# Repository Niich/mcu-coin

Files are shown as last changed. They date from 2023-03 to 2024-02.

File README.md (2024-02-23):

# mcu-coin
## Design Goals
- make a device that is similare in form factor to military challange coins
- production cost needs to be in the range of traditional coins ($5-$15)

## V1.0 features
- based on ESP32C3
- 100mAh 302020 battery
- 7 addressable RGBs
- 2 GPIO buttons
- hardware power on/off and boot select **
    - to reduce power draw when off and to guard against bad firmare bricking the device since once it is assembled, battery soldered in and parts glued together, removing power to reset device would be very difficult.
- USB charging
- wireless charging ***
- WiFi ***
- bluetooth ***

** not working on original design but manual fix found

*** Currently not working

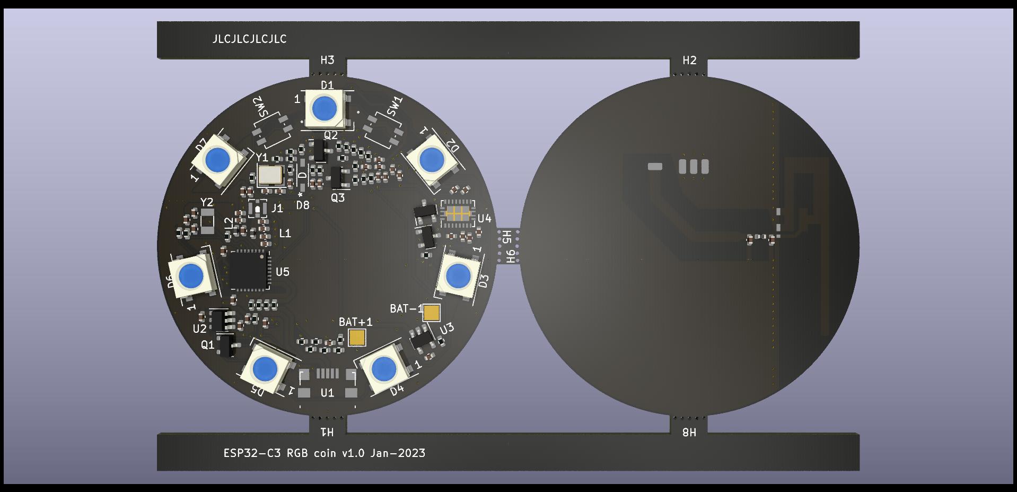
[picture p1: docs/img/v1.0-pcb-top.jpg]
pcb top view

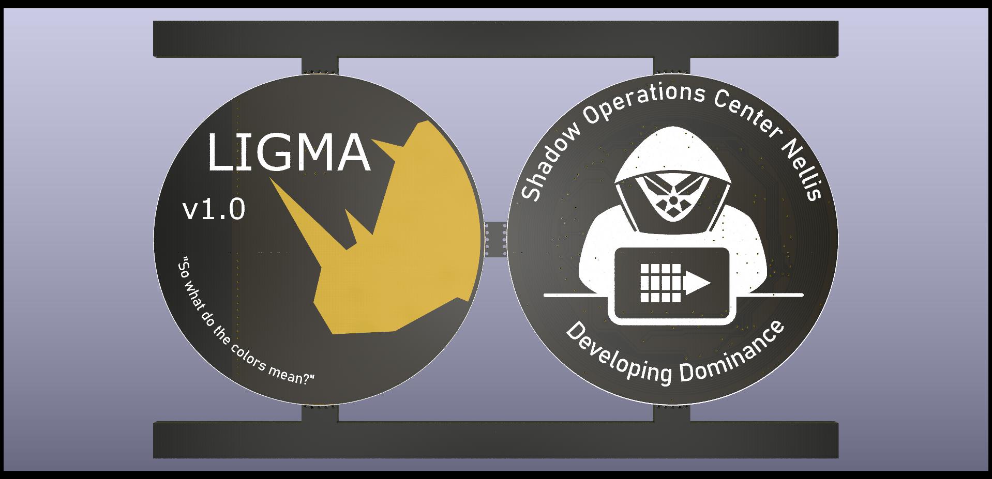
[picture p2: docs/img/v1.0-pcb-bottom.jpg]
pcb bottom view

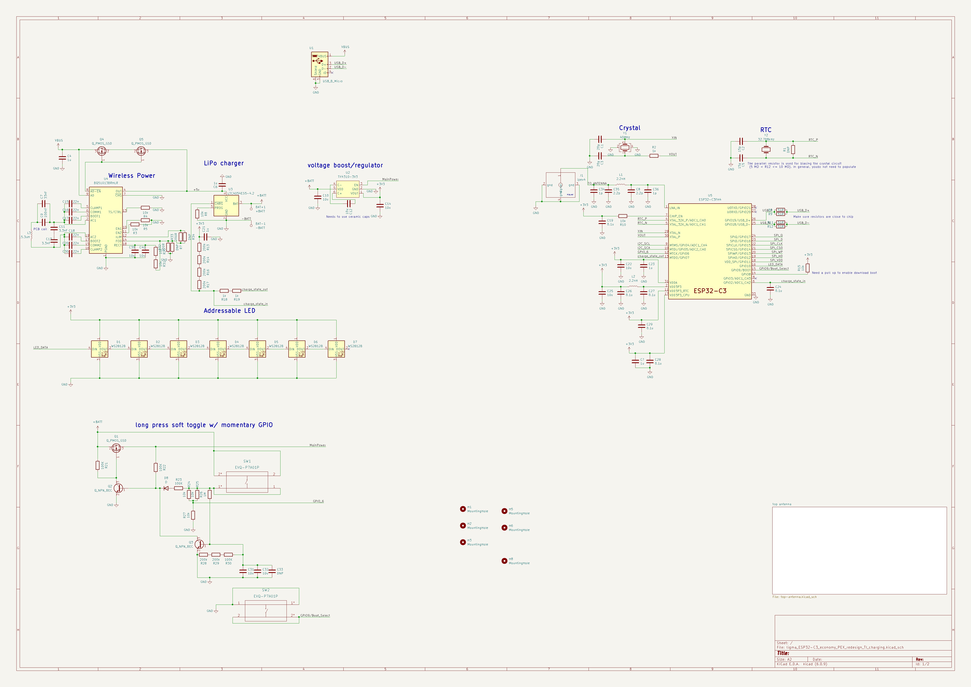
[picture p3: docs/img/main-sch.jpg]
schematic main

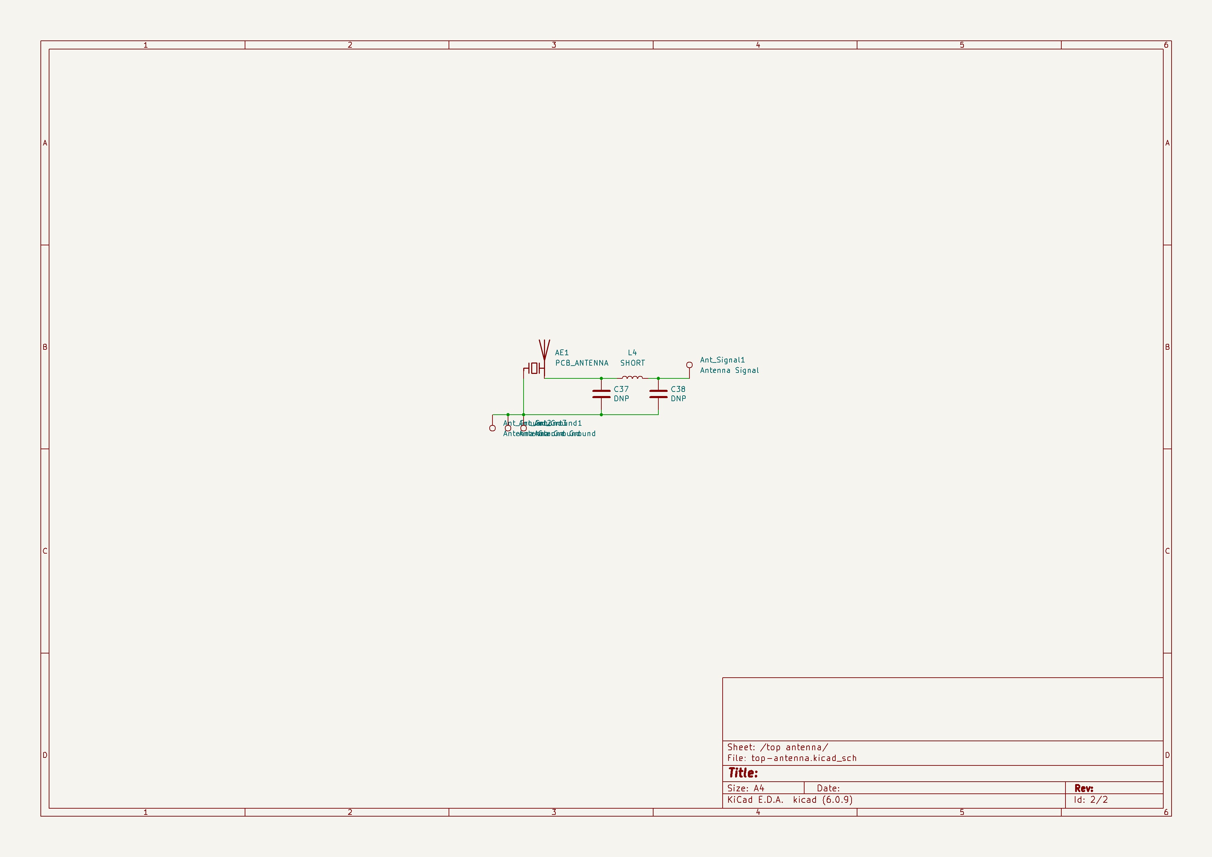
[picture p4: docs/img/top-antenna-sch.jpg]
schematic antenna


## v1.0 known issues
- ✅ SW2 boot select button/GPIO9 
    - **Expected:** when held during boot ESP enters flashing mode.
    - **Observed:** device does not enter boot mode when button is held during boot.
    - **Fix:** After reviewing the ESP docs and the schematic issue was found to be that the button was connected to 3.3v instead of ground. Fixed by cutting trace to +3.3 and bridging the pin to the ground plane.
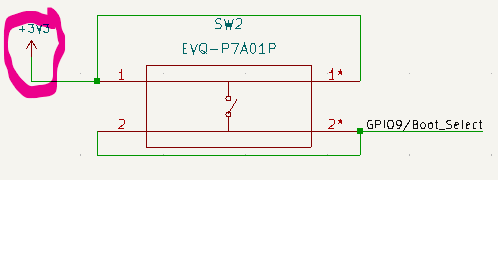
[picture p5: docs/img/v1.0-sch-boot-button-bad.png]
image of incorrect boot select layout
    
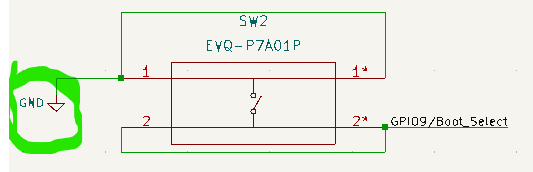
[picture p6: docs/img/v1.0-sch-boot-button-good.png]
image of incorrect boot select layout
    
- ✅ SW1 on-off/GPIO6 
    - **Expected:** when device is off pressing this button should turn on the device. while device is active quick presses should be detected on GPIO6. Long pressing when "on" should turn off the device. 
    - **Observed:** Button does not turn the device on. but once on the press can be detected on GPIO6 and long press does turn the device off.
    - **Fix:** After reviewing the schematic issue was found to be that the button was connected to "MainPower" instead of +BATT. meaning that when the device is off there is no voltage on the switch so pressing it did nothing. Fix is connecting the button to +BATT and cutting trace to "MainPower"
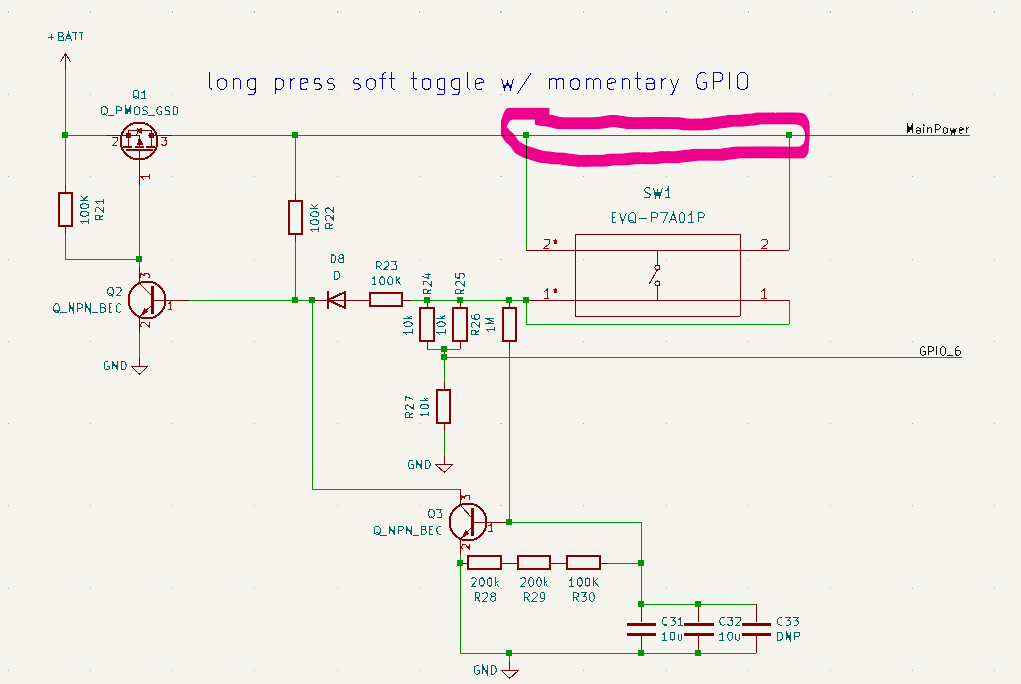
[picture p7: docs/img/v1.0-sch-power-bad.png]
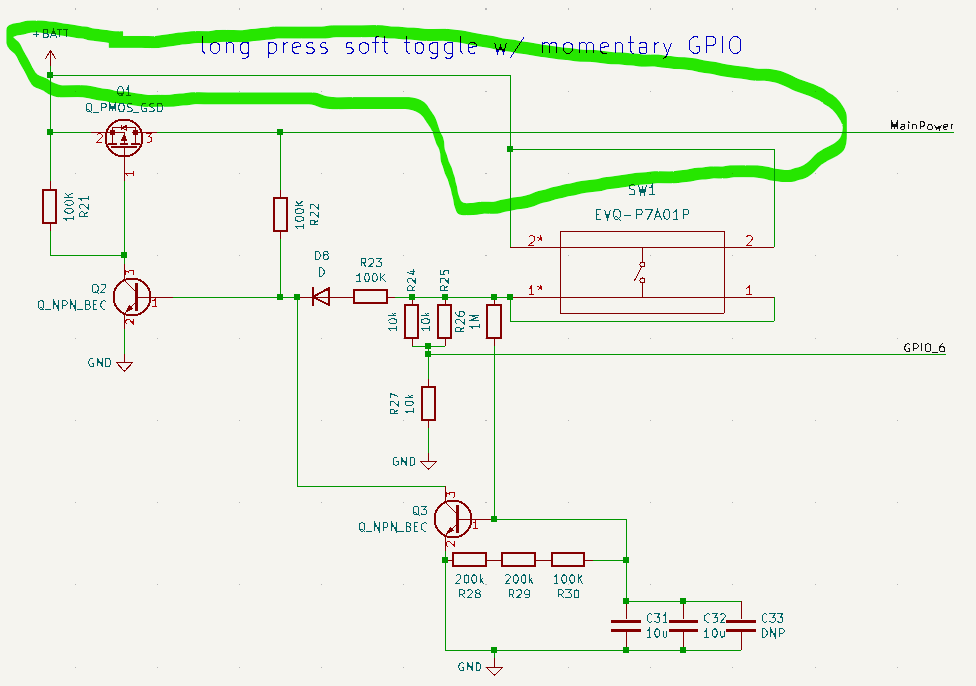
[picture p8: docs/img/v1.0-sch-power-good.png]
    
- ❌ Wireless charging
    - **Expected:** when device placed on wireless charging pad it charges
    - **Observed:** Pad detects device but power delivery never stabalises it seems to be failing the negotiation. Issue has been observed on two differant wireless power transmitters
    - **Fix:** NONE. This is due to poor efficiency. If placed just right, wireless charging will work, but devices get VERY hot. To resolve this, the coil needs to be measured and revised in future designs. Additionally, the QI standard specifies a ferite layer behind the coil, which is not possible with the current placement of the coil.
- ❌ 2.4Ghz wireless (WifI/bluetooth)
    - **Expected:** device connects to WiFi.
    - **Observed:** When 2.4Ghz functions are enabled in firmware the device crashes. 
    - **Fix:** NONE. This is related to the luckup/crashing. When WiFi is activated, it interferes with the main clock and causes the device to lockup/crash.
- ❌ Crashing and hard locks
    - **Expected:** Device runs coninualy until turned of or battery is drained.
    - **Observed:** The device runs for a while but randomly locks up and requires a restart. The issue seems worse when LEDs are at full power.
    - **Fix:** NONE: This is caused by bad placement and routing of the main clock signal. Due to poor design, there is interferance and cross-talk that degrade the clock signal and cause CPU lockup.
- [ ] Acrylic spacer and diffuser
    - **Expected:** Top and bottom PCB are seperated and atteched to a 3mm acrylic spacer.
    - **Observed:** Although the 302020 battery is listed as 3mm thick it is actualy slightly larger so the acrylic part is not thick enought to connect both sides without bending and placing pressure on the LiPo battery
    - **Ideas:** Make a thicker spacer. 1/8" might be ehough since that is 3.17mm

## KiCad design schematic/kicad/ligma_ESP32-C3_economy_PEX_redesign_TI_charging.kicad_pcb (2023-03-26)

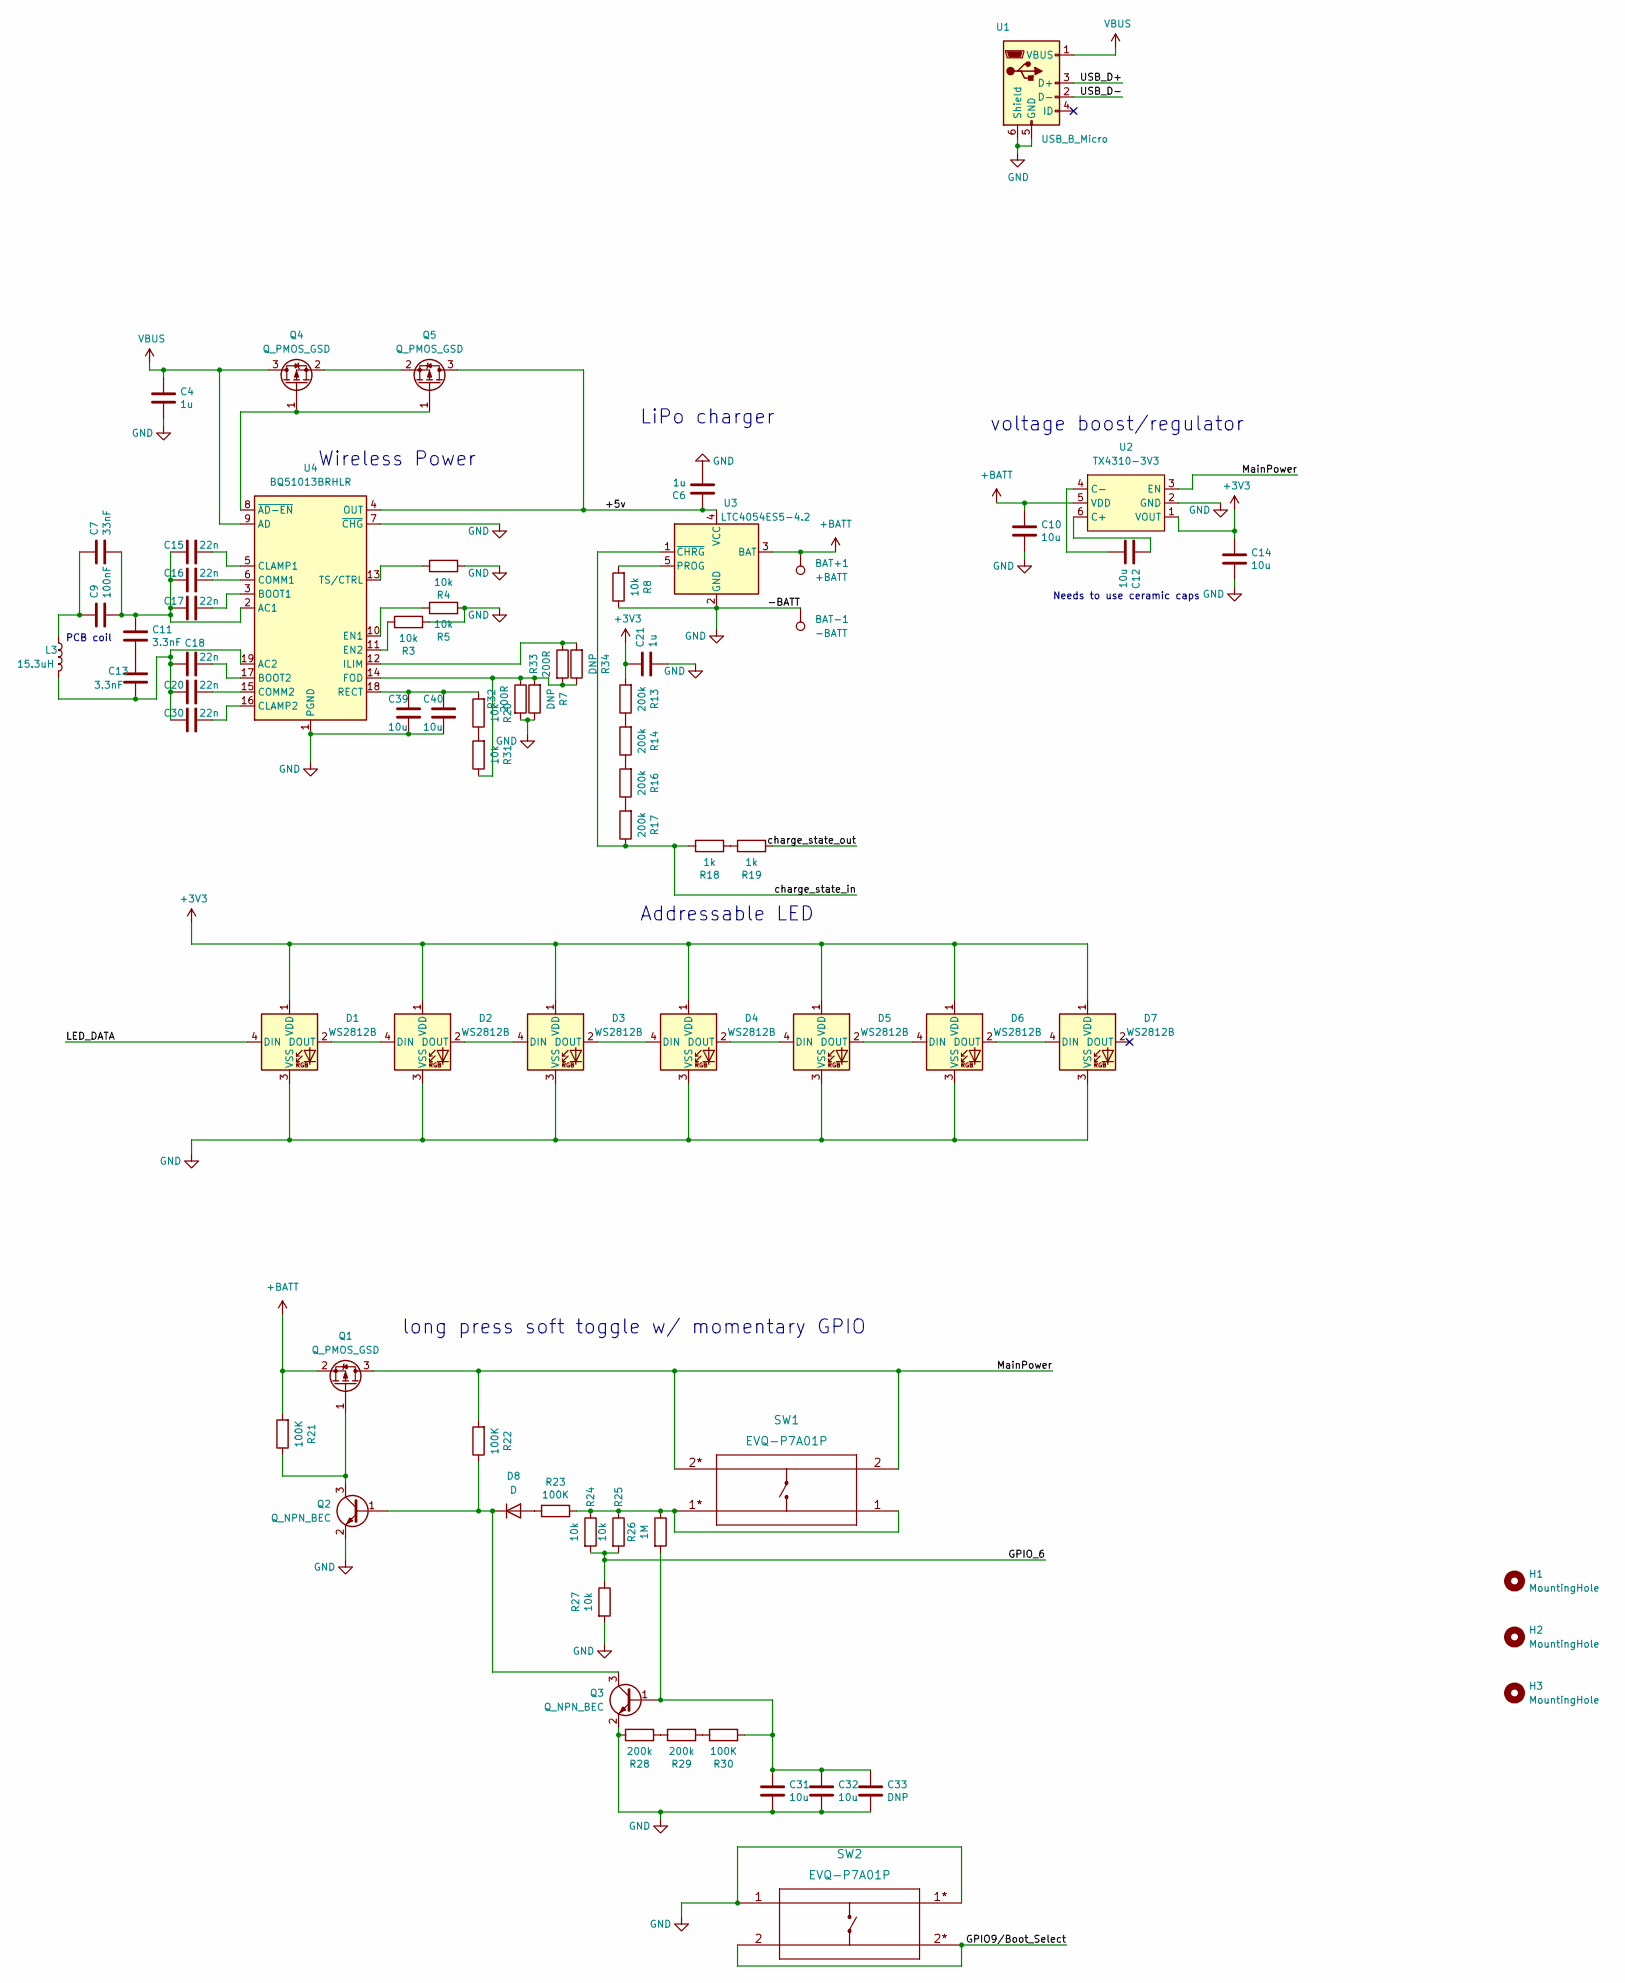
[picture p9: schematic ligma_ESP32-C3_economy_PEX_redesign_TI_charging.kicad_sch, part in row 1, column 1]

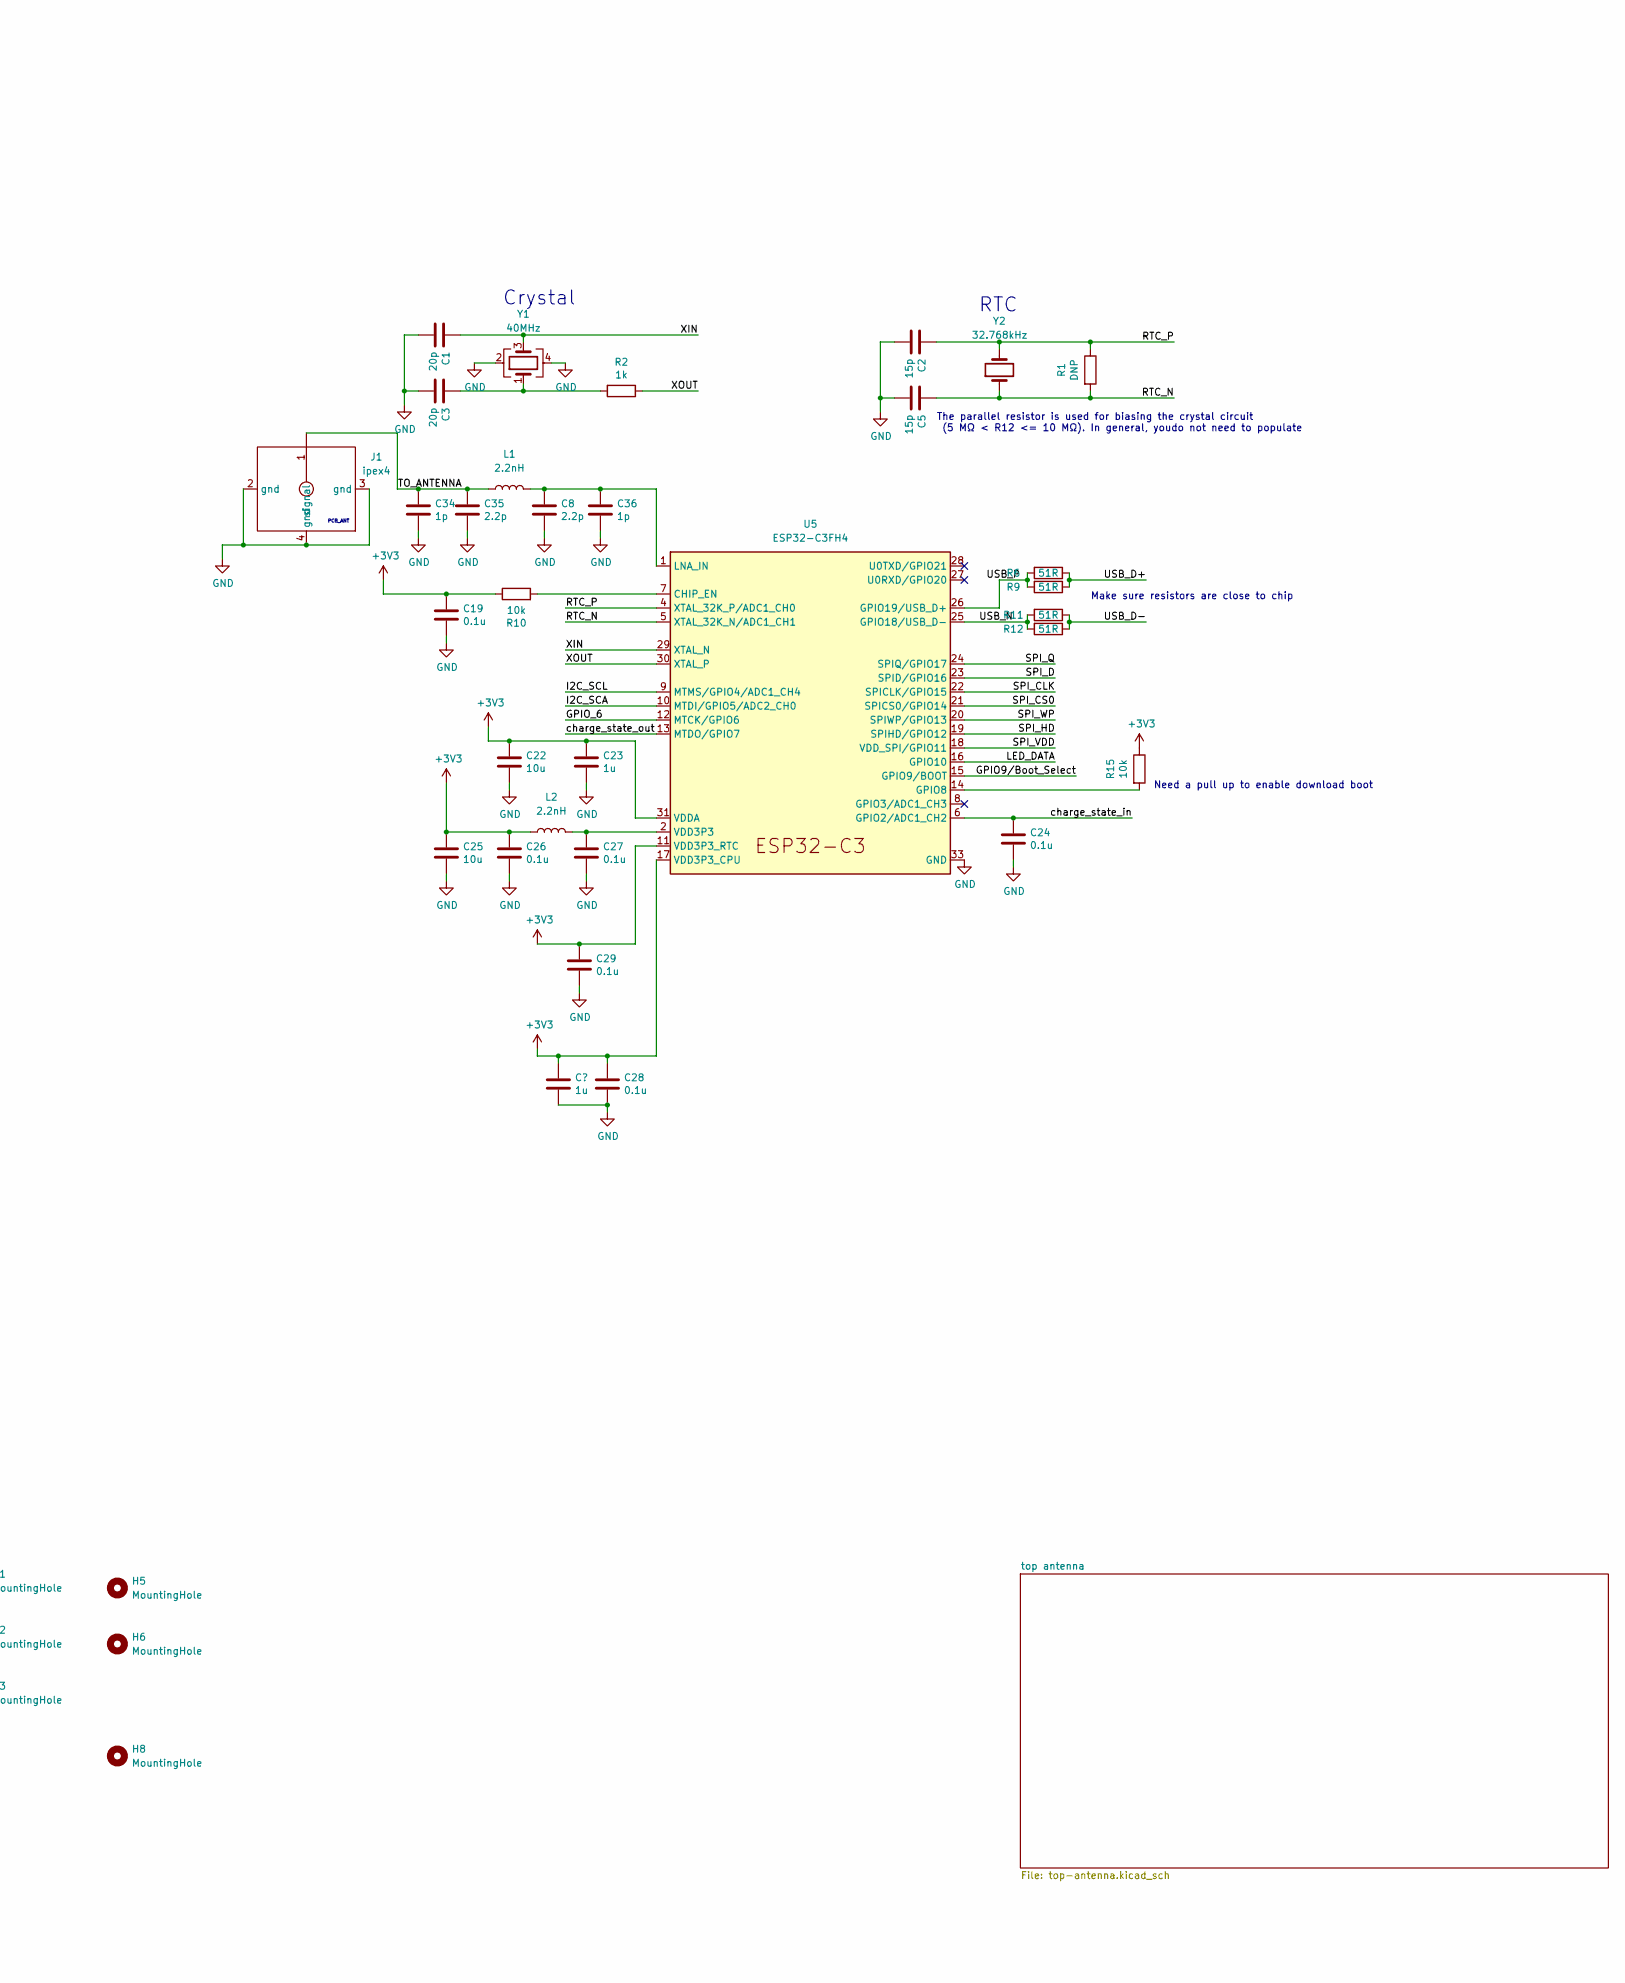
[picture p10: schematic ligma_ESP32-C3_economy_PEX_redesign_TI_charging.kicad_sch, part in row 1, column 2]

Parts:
BAT+1: +BATT; TestPoint_Pad_2.0x2.0mm
BAT-1: -BATT; TestPoint_Pad_2.0x2.0mm
C1, C3: 20p; C_0402_1005Metric; MFR.Part # 0402CG200J500NT; LCSC Part # C1554
C2, C5: 15p; C_0402_1005Metric; MFR.Part # 0402CG150J500NT; LCSC Part # C1548
C4, C6, C21, C23: 1u; C_0402_1005Metric; MFR.Part # CL05A105KA5NQNC; LCSC Part # C52923
C7: 33nF; C_0402_1005Metric; MFR.Part # C1585; LCSC Part # C1585
C8, C35: 2.2p; C_0402_1005Metric; MFR.Part # 0402CG2R2C500NT; LCSC Part # C1559
C9: 100nF; C_0402_1005Metric; MFR.Part # CL05B104KB54PNC; LCSC Part # C307331
C10, C12, C14, C22, C25, C31, C32, C39, C40: 10u; C_0402_1005Metric; MFR.Part # CL05A106MQ5NUNC; LCSC Part # C15525
C11, C13: 3.3nF; C_0402_1005Metric; MFR.Part # CL05B332KB5NNNC; LCSC Part # C26404
C15, C16, C17, C18, C20, C30: 22n; C_0402_1005Metric; MFR.Part # 0402B223K500NT; LCSC Part # C1532
C19, C24, C26, C27, C28, C29: 0.1u; C_0402_1005Metric; MFR.Part # CL05B104KB54PNC; LCSC Part # C307331
C33: DNP; C_0402_1005Metric
C34, C36: 1p; C_0402_1005Metric; MFR.Part # 0402CG1R0C500NT; LCSC Part # C1550
D1, D2, D3, D4, D5, D6, D7: WS2812B; LED_WS2812B_PLCC4_5.0x5.0mm_P3.2mm; MFR.Part # WS2812E-V5; LCSC Part # C2920042
D8: D; SOD_123; MFR.Part # B5819W SL; LCSC Part # C8598
H1, H2, H3, H5, H6, H8: MountingHole; coin-mouse-bite
J1: ipex4; HC-RF-IPEX2020-04; MFR.Part # HC-RF-IPEX2020-04; LCSC Part # C2894921
L1, L2: 2.2nH; L_0402_1005Metric; MFR.Part # CLH1005T-2N2S-S; LCSC Part # C108254
L3: 15.3uH; 15.3uH-coil
Q1, Q4, Q5: Q_PMOS_GSD; SOT-23; MFR.Part # SI2301CDS-T1-GE3; LCSC Part # C10487
Q2, Q3: Q_NPN_BEC; SOT-23; MFR.Part # FHS3904-ME; LCSC Part # C336147
R1, R7, R34: DNP; R_0402_1005Metric
R2, R18, R19: 1k; R_0402_1005Metric; MFR.Part # 0402WGF1001TCE; LCSC Part # C11702
R3, R4, R5: 10k; R_0402_1005Metric; MFR.Part # 0402WGF1000TCE; LCSC Part # C25744
R6, R9, R11, R12: 51R; R_0402_1005Metric; MFR.Part # 0402WGF5100TCE; LCSC Part # C25123
R8, R10, R15, R20, R24, R25, R27, R31: 10k; R_0402_1005Metric; MFR.Part # 0402WGF1002TCE; LCSC Part # C25744
R13, R14, R16, R17, R28, R29: 200k; R_0402_1005Metric; MFR.Part # 0402WGF2003TCE; LCSC Part # C25764
R21, R22, R23, R30: 100K; R_0402_1005Metric; MFR.Part # 0402WGF1003TCE; LCSC Part # C25741
R26: 1M; R_0402_1005Metric; MFR.Part # 0402WGF1004TCE; LCSC Part # C26083
R32, R33: 200R; R_0402_1005Metric; MFR.Part # 0402WGF2000TCE; LCSC Part # C25087
SW1, SW2: EVQ-P7A01P; MFR.Part # EVQP7A01P; LCSC Part # C79167
U1: USB_B_Micro; USB-Micro-B-BTC-MC5S-42; MFR.Part # BTC-MC5S-42; LCSC Part # C2908213
U2: TX4310-3V3; SOT-23-6; MFR.Part # TX4310B; LCSC Part # C448640
U3: LTC4054ES5-4.2; TSOT-23-5; MFR.Part # TP4054-42-SOT25R; LCSC Part # C32574
U4: BQ51013BRHLR; Texas_VQFN-RHL-20; MFR.Part # BQ51013BRHLR; LCSC Part # C55663
U5: ESP32-C3FH4; QFN-32-1EP_5x5mm_P0.5mm_EP3.45x3.45mm; MFR.Part # ESP32-C3FH4; LCSC Part # C2858491
Y1: 40MHz; Crystal_SMD_3225-4Pin_3.2x2.5mm; MFR.Part # 3S40000131; LCSC Part # C516573
Y2: 32.768kHz; Crystal_SMD_3215-2Pin_3.2x1.5mm; MFR.Part # Q13FC1350000400; LCSC Part # C32346

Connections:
+BATT: BAT+1.1, C10.1, Q1.2 (S), R21.2, U2.5 (VDD), U3.3 (BAT)
/+5v: C6.1, Q5.3 (D), U3.4 (VCC), U4.4 (OUT)
/GPIO9/Boot_Select: SW2.2, SW2.2*, U5.15 (GPIO9/BOOT)
/GPIO_6: R24.2, R25.2, R27.1, U5.12 (MTCK/GPIO6)
/I2C_SCA: U5.10 (MTDI/GPIO5/ADC2_CH0)
/I2C_SCL: U5.9 (MTMS/GPIO4/ADC1_CH4)
/LED_DATA: D1.4 (DIN), U5.16 (GPIO10)
/MainPower: Q1.3 (D), R22.2, SW1.2, SW1.2*, U2.3 (EN)
/RTC_N: C5.1, R1.2, U5.5 (XTAL_32K_N/ADC1_CH1), Y2.1
/RTC_P: C2.1, R1.1, U5.4 (XTAL_32K_P/ADC1_CH0), Y2.2
/SPI_CLK: U5.22 (SPICLK/GPIO15)
/SPI_CS0: U5.21 (SPICS0/GPIO14)
/SPI_D: U5.23 (SPID/GPIO16)
/SPI_HD: U5.19 (SPIHD/GPIO12)
/SPI_Q: U5.24 (SPIQ/GPIO17)
/SPI_VDD: U5.18 (VDD_SPI/GPIO11)
/SPI_WP: U5.20 (SPIWP/GPIO13)
/TO_ANTENNA: C34.1, C35.1, J1.1 (signal), L1.1
/USB_D+: R6.1, R9.1, U1.3 (D+)
/USB_D-: R11.1, R12.1, U1.2 (D-)
/USB_N: R11.2, R12.2, U5.25 (GPIO18/USB_D-)
/USB_P: R6.2, R9.2, U5.26 (GPIO19/USB_D+)
/XIN: C1.1, U5.29 (XTAL_N), Y1.3
/XOUT: R2.1, U5.30 (XTAL_P)
/charge_state_in: C24.1, R17.1, R18.1, U3.1 (~CHRG), U5.6 (GPIO2/ADC1_CH2)
/charge_state_out: R19.2, U5.13 (MTDO/GPIO7)
GND: BAT-1.1, C1.2, C2.2, C3.2, C4.2, C5.2, C6.2, C8.2, C10.2, C14.2, C19.2, C21.2, C22.2, C23.2, C24.2, C25.2, C26.2, C27.2, C28.2, C29.2, C31.2, C32.2, C33.2, C34.2, C35.2, C36.2, C39.2, C40.2, D1.3 (VSS), D2.3 (VSS), D3.3 (VSS), D4.3 (VSS), D5.3 (VSS), D6.3 (VSS), D7.3 (VSS), J1.2 (gnd), J1.3 (gnd), J1.4 (gnd), Q2.2 (E), Q3.2 (E), R3.2, R4.2, R5.2, R7.1, R8.1, R27.2, R28.1, R32.2, U1.5 (GND), U1.6 (Shield), U2.2 (GND), U3.2 (GND), U4.1 (PGND), U4.7 (~CHG), U4.20 (PGND), U4.21 (PGND), U5.33 (GND), Y1.2, Y1.4
unnamed: C3.1, R2.2, Y1.1
unnamed: C7.1, C9.1, L3.1
unnamed: C7.2, C9.2, C11.1, C15.1, C16.1, C17.1, U4.2 (AC1)
unnamed: C11.2, C13.1
unnamed: C12.1, U2.6 (C+)
unnamed: C12.2, U2.4 (C-)
unnamed: C13.2, C18.1, C20.1, C30.1, L3.2, U4.19 (AC2)
unnamed: C15.2, U4.5 (CLAMP1)
unnamed: C16.2, U4.6 (COMM1)
unnamed: C17.2, U4.3 (BOOT1)
unnamed: C18.2, U4.17 (BOOT2)
unnamed: C20.2, U4.15 (COMM2)
unnamed: C27.1, L2.2, U5.2 (VDD3P3), U5.3 (VDD3P3)
unnamed: C30.2, U4.16 (CLAMP2)
unnamed: C31.1, C32.1, C33.1, Q3.1 (B), R26.2, R30.2
unnamed: C8.1, C36.1, L1.2, U5.1 (LNA_IN)
unnamed: C39.1, C40.1, R20.2, U4.18 (RECT)
unnamed: D1.2 (DOUT), D2.4 (DIN)
unnamed: D2.2 (DOUT), D3.4 (DIN)
unnamed: D3.2 (DOUT), D4.4 (DIN)
unnamed: D4.2 (DOUT), D5.4 (DIN)
unnamed: D5.2 (DOUT), D6.4 (DIN)
unnamed: D6.2 (DOUT), D7.4 (DIN)
unnamed: D8.1 (K), Q2.1 (B), Q3.3 (C), R22.1
unnamed: D8.2 (A), R23.2
unnamed: Q1.1 (G), Q2.3 (C), R21.1
unnamed: Q4.1 (G), Q5.1 (G), U4.8 (~AD-EN)
unnamed: Q4.2 (S), Q5.2 (S)
unnamed: R3.1, U4.11 (EN2)
unnamed: R4.1, U4.13 (TS/CTRL)
unnamed: R5.1, U4.10 (EN1)
unnamed: R7.2, R31.1, R32.1, R33.2, R34.1, U4.14 (FOD)
unnamed: R8.2, U3.5 (PROG)
unnamed: R10.2, U5.7 (CHIP_EN)
unnamed: R13.1, R14.2
unnamed: R14.1, R16.2
unnamed: R15.2, U5.14 (GPIO8)
unnamed: R16.1, R17.2
unnamed: R18.2, R19.1
unnamed: R20.1, R31.2
unnamed: R23.1, R24.1, R25.1, R26.1, SW1.1, SW1.1*
unnamed: R28.2, R29.1
unnamed: R29.2, R30.1
unnamed: R33.1, R34.2, U4.12 (ILIM)
VBUS: C4.1, Q4.3 (D), U1.1 (VBUS), U4.9 (AD)

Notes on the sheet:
LiPo charger
PCB_ANT
voltage boost/regulator
Crystal
Needs to use ceramic caps
Wireless Power
PCB coil
Need a pull up to enable download boot
RTC
The parallel resistor is used for biasing the crystal circuit (5 MΩ < R12 <= 10 MΩ). In general, youdo not need to populate
long press soft toggle w/ momentary GPIO
Make sure resistors are close to chip
Addressable LED

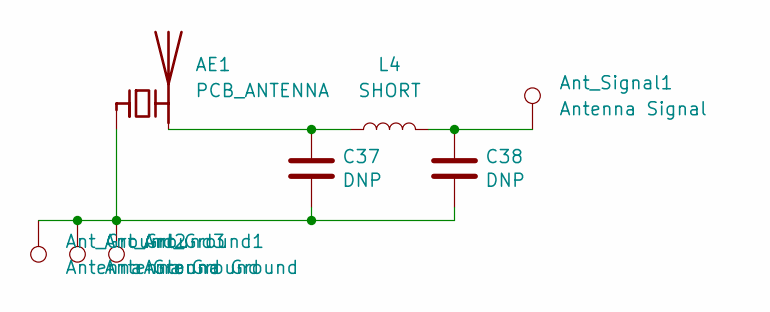
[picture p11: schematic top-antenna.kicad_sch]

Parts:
AE1: PCB_ANTENNA; 2.4_Ti
Ant_Ground1, Ant_Ground2, Ant_Ground3: Antenna Ground; SolderWirePad_1x01_SMD_1x2mm
Ant_Signal1: Antenna Signal; SolderWirePad_1x01_SMD_1x2mm
C37, C38: DNP; C_0402_1005Metric
L4: SHORT; L_0402_1005Metric; LCSC Part # C17168

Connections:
unnamed: AE1.1 (FEED), Ant_Ground1.1, Ant_Ground2.1, Ant_Ground3.1, C37.2, C38.2
unnamed: AE1.2 (PCB_Trace), C37.1, L4.1
unnamed: Ant_Signal1.1, C38.1, L4.2

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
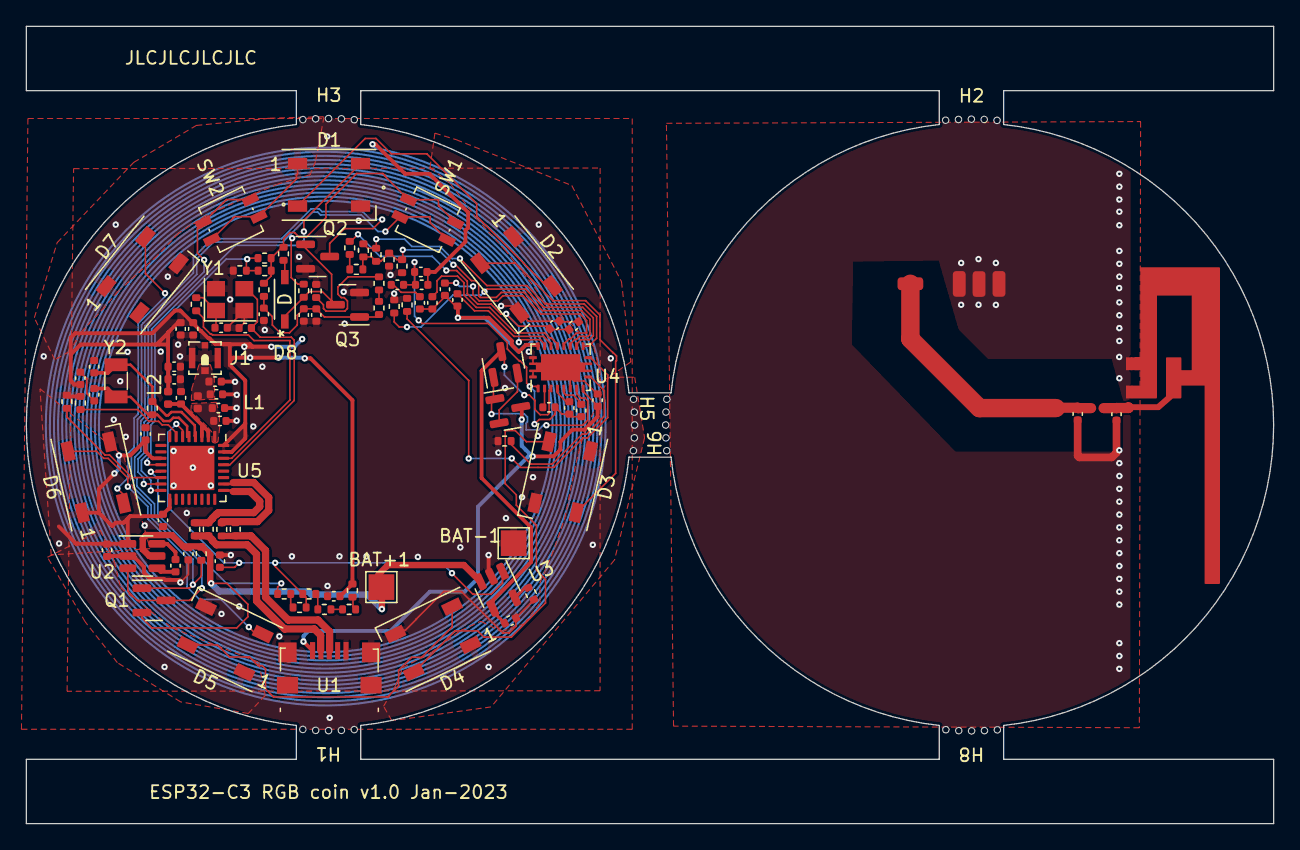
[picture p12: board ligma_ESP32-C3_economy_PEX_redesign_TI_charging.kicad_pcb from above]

Board: 2 copper layers, 97.0 x 62.0 mm, 114 parts (1 on the bottom side), 67 nets.

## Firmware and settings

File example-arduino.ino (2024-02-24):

// Simple demonstration on using an input device to trigger changes on your
// NeoPixels. Wire a momentary push button to connect from ground to a
// digital IO pin. When the button is pressed it will change to a new pixel
// animation. Initial state has all pixels off -- press the button once to
// start the first animation. As written, the button does not interrupt an
// animation in-progress, it works only when idle.

#include <Adafruit_NeoPixel.h>
#ifdef __AVR__
 #include <avr/power.h> // Required for 16 MHz Adafruit Trinket
#endif

// Digital IO pin connected to the button. This will be driven with a
// pull-up resistor so the switch pulls the pin to ground momentarily.
// On a high -> low transition the button press logic will execute.
#define BUTTON_PIN   9

#define PIXEL_PIN    10  // Digital IO pin connected to the NeoPixels.

#define PIXEL_COUNT 7  // Number of NeoPixels

// Declare our NeoPixel strip object:
Adafruit_NeoPixel strip(PIXEL_COUNT, PIXEL_PIN, NEO_GRB + NEO_KHZ800);
// Argument 1 = Number of pixels in NeoPixel strip
// Argument 2 = Arduino pin number (most are valid)
// Argument 3 = Pixel type flags, add together as needed:
//   NEO_KHZ800  800 KHz bitstream (most NeoPixel products w/WS2812 LEDs)
//   NEO_KHZ400  400 KHz (classic 'v1' (not v2) FLORA pixels, WS2811 drivers)
//   NEO_GRB     Pixels are wired for GRB bitstream (most NeoPixel products)
//   NEO_RGB     Pixels are wired for RGB bitstream (v1 FLORA pixels, not v2)
//   NEO_RGBW    Pixels are wired for RGBW bitstream (NeoPixel RGBW products)

boolean oldState = HIGH;
int     mode     = 0;    // Currently-active animation mode, 0-9
int     sat     = 255;    // Currently-active animation mode, 0-9
int     val     = 60;    // Currently-active animation mode, 0-9

void setup() {
  pinMode(BUTTON_PIN, INPUT_PULLUP);
  strip.begin(); // Initialize NeoPixel strip object (REQUIRED)
  strip.show();  // Initialize all pixels to 'off'
}

void loop() {
  // Get current button state.
  boolean newState = digitalRead(BUTTON_PIN);

  // Check if state changed from high to low (button press).
  if((newState == LOW) && (oldState == HIGH)) {
    // Short delay to debounce button.
    delay(20);
    // Check if button is still low after debounce.
    newState = digitalRead(BUTTON_PIN);
    if(newState == LOW) {      // Yes, still low
      if(++mode > 8) mode = 0; // Advance to next mode, wrap around after #8
      switch(mode) {           // Start the new animation...
        case 0:
          colorWipe(strip.Color(  0,   0,   0), 50);    // Black/off
          break;
        case 1:
          colorWipe(strip.Color(255,   0,   0), 50);    // Red
          break;
        case 2:
          colorWipe(strip.Color(  0, 255,   0), 50);    // Green
          break;
        case 3:
          colorWipe(strip.Color(  0,   0, 255), 50);    // Blue
          break;
        case 4:
          theaterChase(strip.Color(255, 255, 255), 50); // White
          break;
        case 5:
          theaterChase(strip.Color(255,   0,   0), 50); // Red
          break;
        case 6:
          theaterChase(strip.Color(  0,   0, 255), 50); // Blue
          break;
        case 7:
          rainbow(20);
          break;
        case 8:
          theaterChaseRainbow(50);
          break;
      }
    }
  }

  // Set the last-read button state to the old state.
  oldState = newState;
}

// Fill strip pixels one after another with a color. Strip is NOT cleared
// first; anything there will be covered pixel by pixel. Pass in color
// (as a single 'packed' 32-bit value, which you can get by calling
// strip.Color(red, green, blue) as shown in the loop() function above),
// and a delay time (in milliseconds) between pixels.
void colorWipe(uint32_t color, int wait) {
  for(int i=0; i<strip.numPixels(); i++) { // For each pixel in strip...
    strip.setPixelColor(i, color);         //  Set pixel's color (in RAM)
    strip.show();                          //  Update strip to match
    delay(wait);                           //  Pause for a moment
  }
}

// Theater-marquee-style chasing lights. Pass in a color (32-bit value,
// a la strip.Color(r,g,b) as mentioned above), and a delay time (in ms)
// between frames.
void theaterChase(uint32_t color, int wait) {
  for(int a=0; a<10; a++) {  // Repeat 10 times...
    for(int b=0; b<3; b++) { //  'b' counts from 0 to 2...
      strip.clear();         //   Set all pixels in RAM to 0 (off)
      // 'c' counts up from 'b' to end of strip in steps of 3...
      for(int c=b; c<strip.numPixels(); c += 3) {
        strip.setPixelColor(c, color); // Set pixel 'c' to value 'color'
      }
      strip.show(); // Update strip with new contents
      delay(wait);  // Pause for a moment
    }
  }
}

// Rainbow cycle along whole strip. Pass delay time (in ms) between frames.
void rainbow(int wait) {
  // Hue of first pixel runs 3 complete loops through the color wheel.
  // Color wheel has a range of 65536 but it's OK if we roll over, so
  // just count from 0 to 3*65536. Adding 256 to firstPixelHue each time
  // means we'll make 3*65536/256 = 768 passes through this outer loop:
  for(long firstPixelHue = 0; firstPixelHue < 3*65536; firstPixelHue += 256) {
    for(int i=0; i<strip.numPixels(); i++) { // For each pixel in strip...
      // Offset pixel hue by an amount to make one full revolution of the
      // color wheel (range of 65536) along the length of the strip
      // (strip.numPixels() steps):
      int pixelHue = firstPixelHue + (i * 65536L / strip.numPixels());
      // strip.ColorHSV() can take 1 or 3 arguments: a hue (0 to 65535) or
      // optionally add saturation and value (brightness) (each 0 to 255).
      // Here we're using just the single-argument hue variant. The result
      // is passed through strip.gamma32() to provide 'truer' colors
      // before assigning to each pixel:
      strip.setPixelColor(i, strip.gamma32(strip.ColorHSV(pixelHue,sat,val)));
    }
    strip.show(); // Update strip with new contents
    delay(wait);  // Pause for a moment
  }
}

// Rainbow-enhanced theater marquee. Pass delay time (in ms) between frames.
void theaterChaseRainbow(int wait) {
  int firstPixelHue = 0;     // First pixel starts at red (hue 0)
  for(int a=0; a<30; a++) {  // Repeat 30 times...
    for(int b=0; b<3; b++) { //  'b' counts from 0 to 2...
      strip.clear();         //   Set all pixels in RAM to 0 (off)
      // 'c' counts up from 'b' to end of strip in increments of 3...
      for(int c=b; c<strip.numPixels(); c += 3) {
        // hue of pixel 'c' is offset by an amount to make one full
        // revolution of the color wheel (range 65536) along the length
        // of the strip (strip.numPixels() steps):
        int      hue   = firstPixelHue + c * 65536L / strip.numPixels();
        uint32_t color = strip.gamma32(strip.ColorHSV(hue,sat,val)); // hue -> RGB
        strip.setPixelColor(c, color); // Set pixel 'c' to value 'color'
      }
      strip.show();                // Update strip with new contents
      delay(wait);                 // Pause for a moment
      firstPixelHue += 65536 / 90; // One cycle of color wheel over 90 frames
    }
  }
}

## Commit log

2023-03-26 add pcb kicad files and first docs img
    [ligma_ESP32-C3_economy_PEX_redesign_TI_charging.kicad_pcb, ligma_ESP32-C3_economy_PEX_redesign_TI_charging.kicad_sch, top-antenna.kicad_sch]
2023-03-26 add project images
    [ligma_ESP32-C3_economy_PEX_redesign_TI_charging.kicad_sch]
2023-03-26 mark PowerSwitch issues as fixed
2023-03-26 add issue about battery and spacer not working together
2024-02-24 Create example-arduino.ino
    add example arduino firmware file that cycles through some color modes.

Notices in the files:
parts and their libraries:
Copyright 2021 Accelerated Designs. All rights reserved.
